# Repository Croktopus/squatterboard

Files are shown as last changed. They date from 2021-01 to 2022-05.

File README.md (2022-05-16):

# Squatterboard

NOTE: THIS PROJECT HAS BEEN SUPPLANTED BY [SQUATTERBOARD2](https://github.com/Croktopus/squatterboard2)

The primary purpose behind this daughterboard is to take up less space "vertically", in addition to using m3 screws (so it can use the same screws I use on the rest of the case) and less screws.

It's also designed to be easily JLC assembled, using basic parts where possible, and the only hand soldering that must be done is the USB and JLC connectors. using the files in the JLC directory, you can get 10 assembled for about $18, though JLC might tack on a $10 "multiple design" tax.

Due to peculiarities of the keyboard i designed this for, it's optimized to be mounted "upside down" with the USB & components on the bottom side, and it's meant to use 1.0mm FR4. Also, the pinout is not at all compatible with the Unified Daughterboard or PCBs which use it.

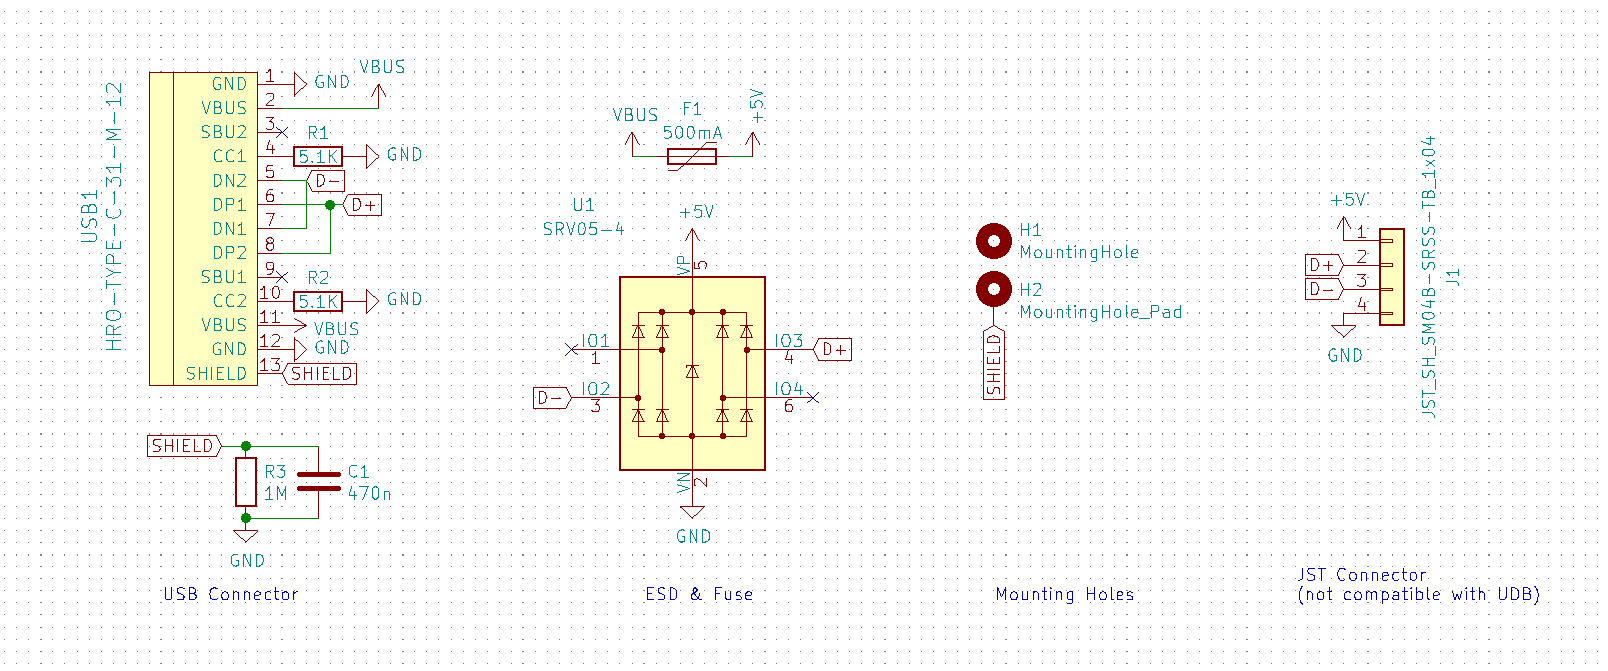
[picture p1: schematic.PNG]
schematic

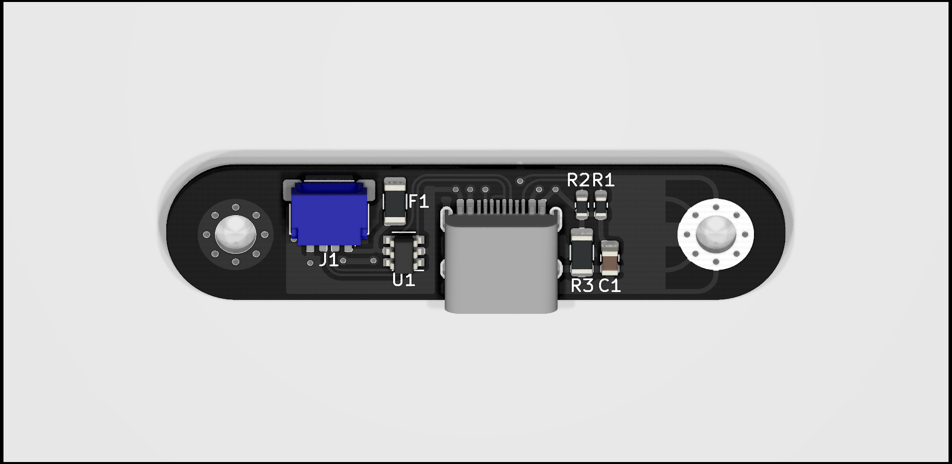
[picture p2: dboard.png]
pcb


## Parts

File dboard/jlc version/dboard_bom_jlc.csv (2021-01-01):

Comment | Designator | Footprint | LCSC Part #
470n | C1,C2 | C_0805_2012Metric | C13967
500mA | F1,F2 | Fuse_1206_3216Metric | C70076
5.1K | R1,R2,R4,R5 | R_0603_1608Metric | C23186
1M | R3,R6 | R_1206_3216Metric | C17927
SRV05-4 | U1,U2 | SOT-23-6 | C85364

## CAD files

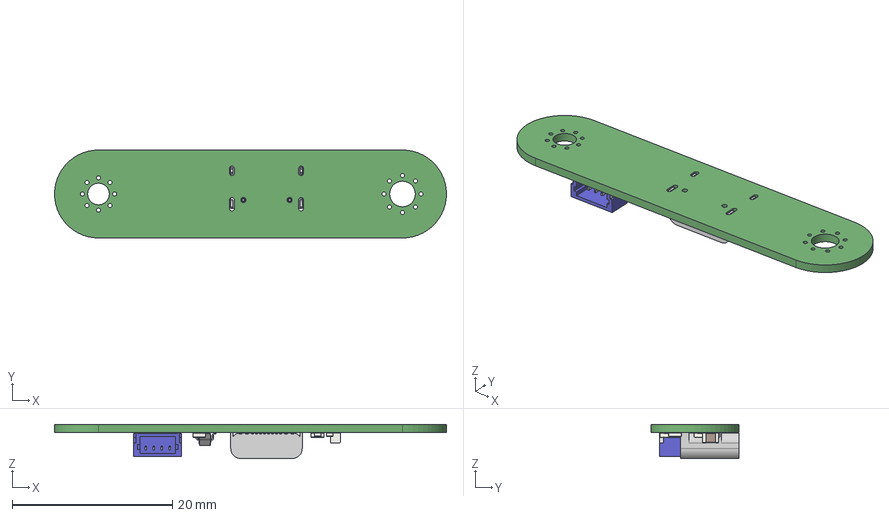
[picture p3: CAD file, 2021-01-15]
dboard/dboardm25.step
49.0 x 11.0 x 4.26 mm

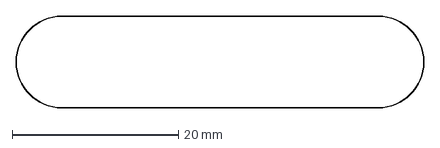
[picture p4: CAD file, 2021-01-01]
dboard/outline.dxf
49.0 x 11.0 mm

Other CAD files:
dboard/dboard.step

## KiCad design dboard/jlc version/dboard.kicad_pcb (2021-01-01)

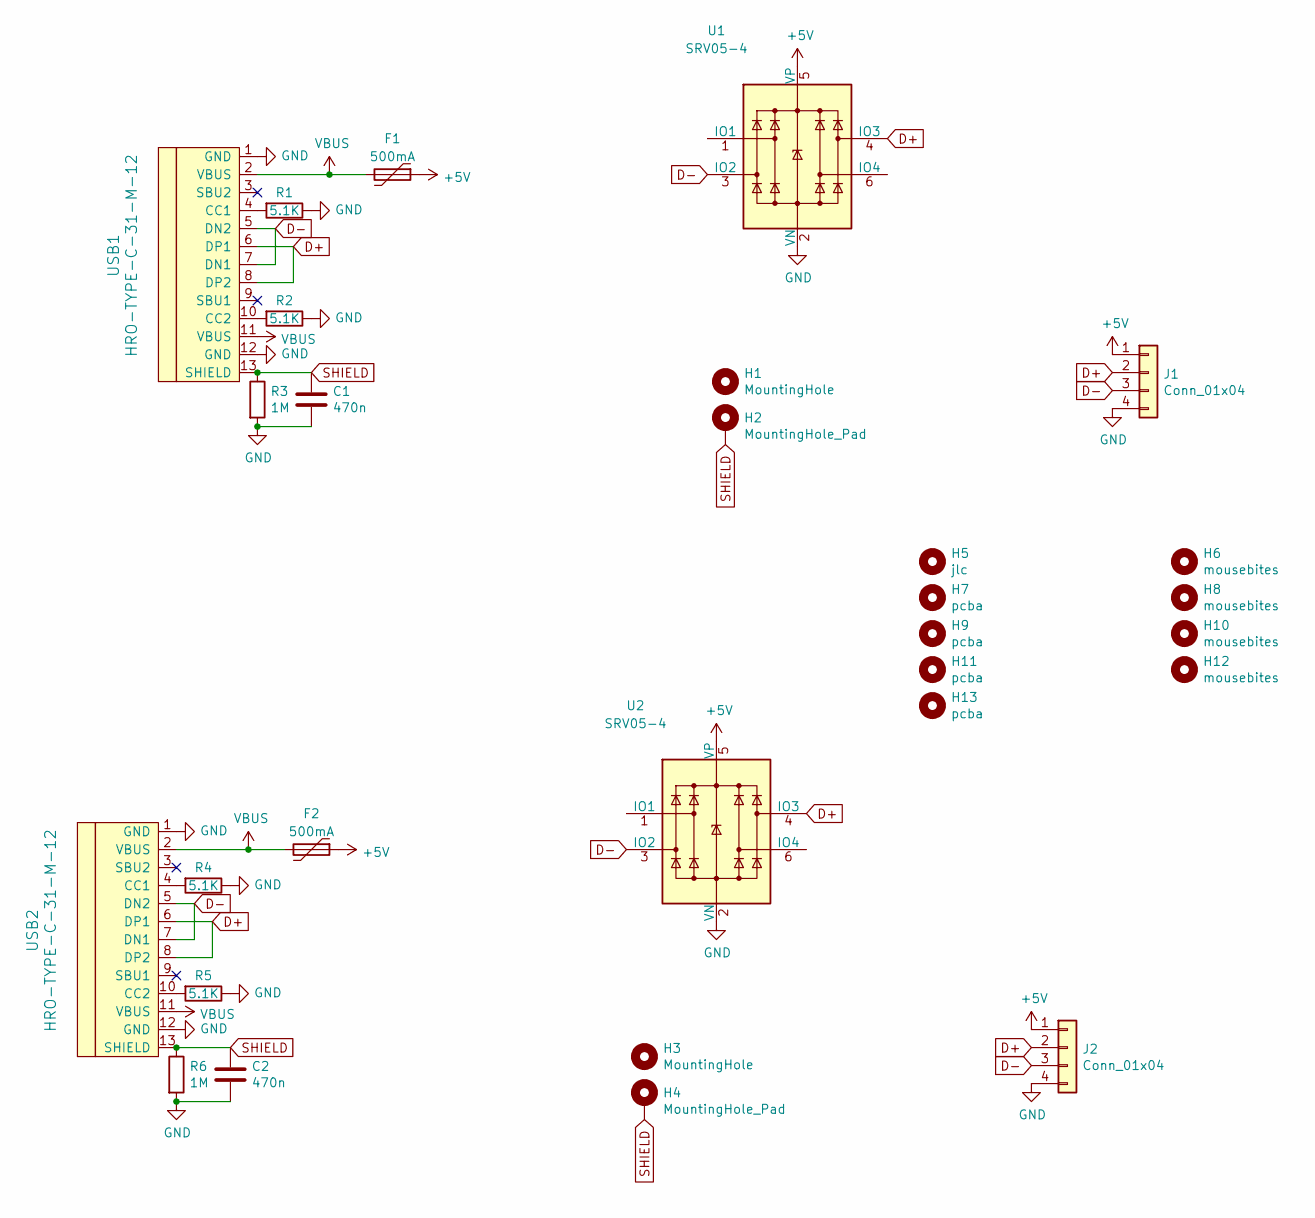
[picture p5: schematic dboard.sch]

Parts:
C1, C2: 470n; C_0805_2012Metric; jlc C13967
F1, F2: 500mA; Fuse_1206_3216Metric; jlc C70076
H1, H3: MountingHole; M3_Via_Hole_NC
H2, H4: MountingHole_Pad; M3_Via_Hole
H5: jlc
H6, H8, H10, H12: mousebites; mousebites-6mm
H7, H9, H11, H13: pcba; JLCPCBA
J1, J2: Conn_01x04; JST_SH_SM04B-SRSS-TB_1x04-1MP_P1.00mm_Horizontal
R1, R2, R4, R5: 5.1K; R_0603_1608Metric; jlc C23186
R3, R6: 1M; R_1206_3216Metric; jlc C17927
U1, U2: SRV05-4; SOT-23-6; jlc C85364
USB1, USB2: HRO-TYPE-C-31-M-12; HRO-TYPE-C-31-M-12-Assembly

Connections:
+5V: F1.1, F2.1, J1.1, J2.1, U1.5 (VP), U2.5 (VP)
D+: J1.2, J2.2, U1.4 (IO3), U2.4 (IO3), USB1.6 (DP1), USB1.8 (DP2), USB2.6 (DP1), USB2.8 (DP2)
D-: J1.3, J2.3, U1.3 (IO2), U2.3 (IO2), USB1.5 (DN2), USB1.7 (DN1), USB2.5 (DN2), USB2.7 (DN1)
GND: C1.2, C2.2, J1.4, J2.4, R1.1, R2.1, R3.2, R4.1, R5.1, R6.2, U1.2 (VN), U2.2 (VN), USB1.1 (GND), USB1.12 (GND), USB2.1 (GND), USB2.12 (GND)
unnamed: R1.2, USB1.4 (CC1)
unnamed: R2.2, USB1.10 (CC2)
unnamed: R4.2, USB2.4 (CC1)
unnamed: R5.2, USB2.10 (CC2)
SHIELD: C1.1, C2.1, H2.1, H4.1, R3.1, R6.1, USB1.13 (SHIELD), USB2.13 (SHIELD)
VBUS: F1.2, F2.2, USB1.2 (VBUS), USB1.11 (VBUS), USB2.2 (VBUS), USB2.11 (VBUS)

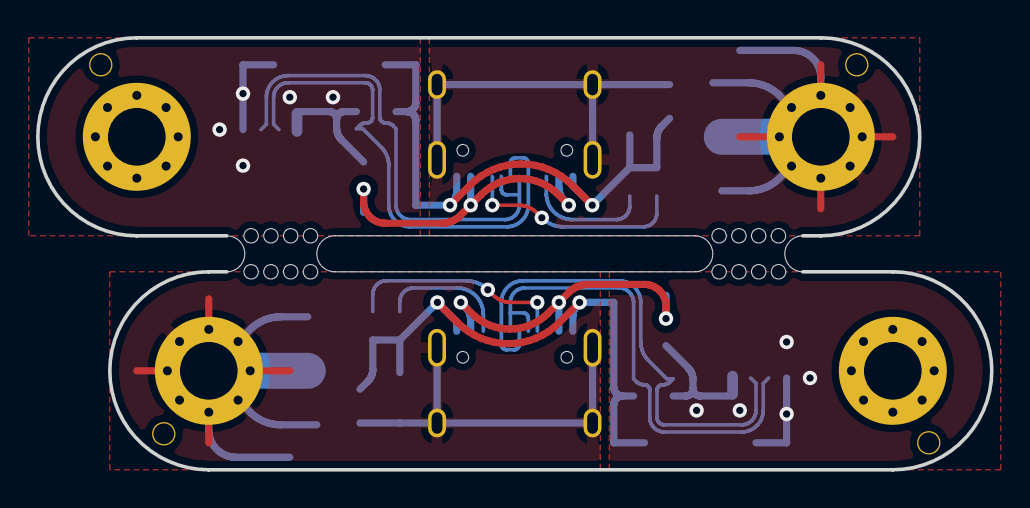
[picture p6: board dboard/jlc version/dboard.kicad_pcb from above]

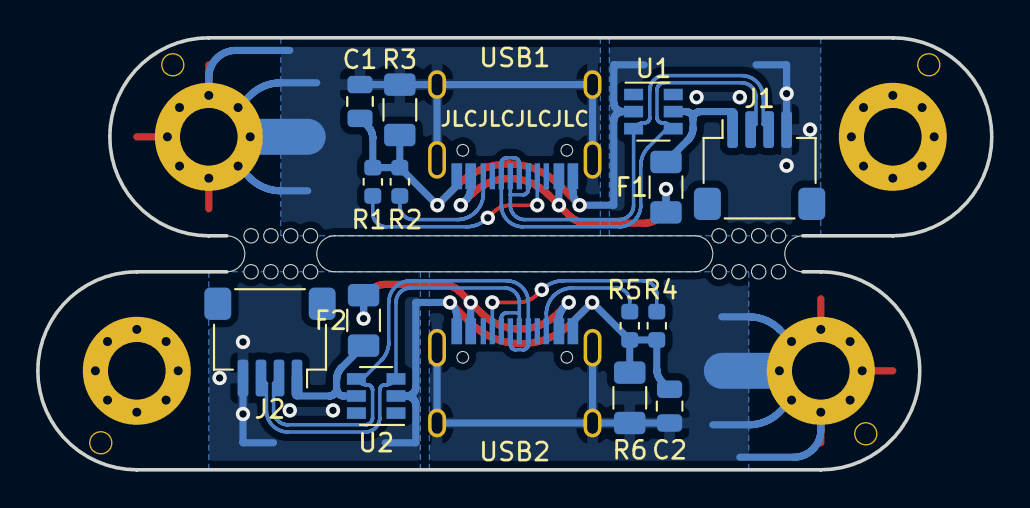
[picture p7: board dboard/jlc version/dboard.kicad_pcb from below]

Board: 2 copper layers, 53.0 x 24.0 mm, 29 parts (17 on the bottom side), 10 nets.

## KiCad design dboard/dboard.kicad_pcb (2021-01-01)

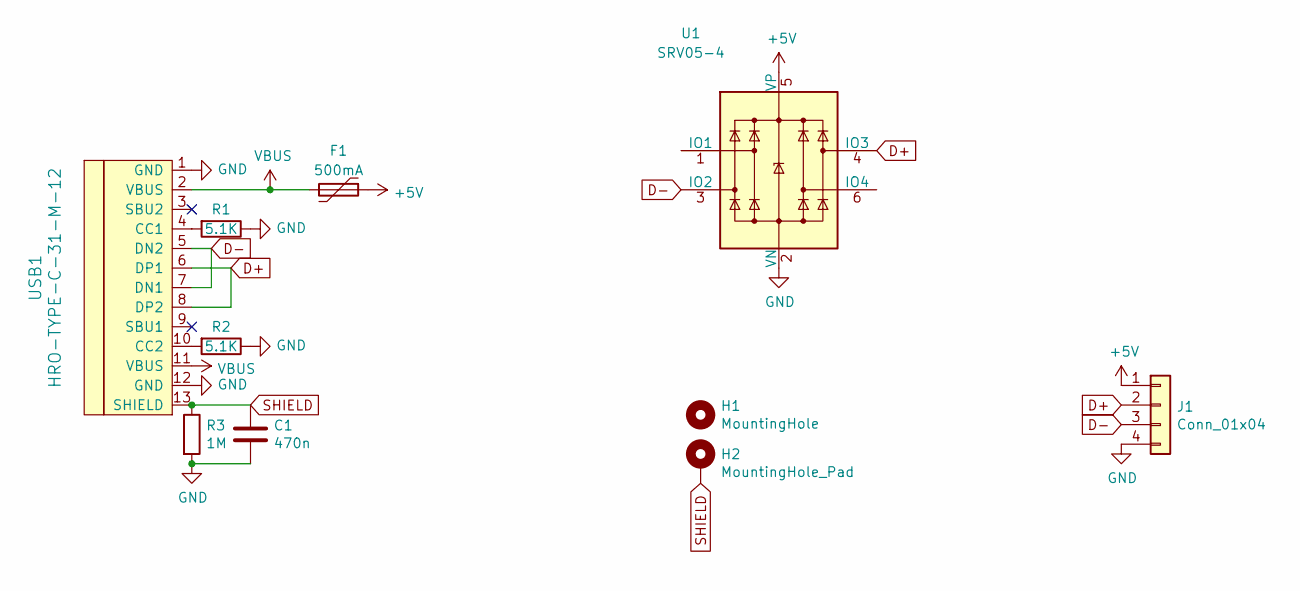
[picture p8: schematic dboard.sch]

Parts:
C1: 470n; C_0805_2012Metric; jlc C13967
F1: 500mA; Fuse_1206_3216Metric; jlc C70076
H1: MountingHole; M3_Via_Hole_NC
H2: MountingHole_Pad; M3_Via_Hole
J1: Conn_01x04; JST_SH_SM04B-SRSS-TB_1x04-1MP_P1.00mm_Horizontal
R1, R2: 5.1K; R_0603_1608Metric; jlc C23186
R3: 1M; R_1206_3216Metric; jlc C17927
U1: SRV05-4; SOT-23-6; jlc C85364
USB1: HRO-TYPE-C-31-M-12; HRO-TYPE-C-31-M-12-Assembly

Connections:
+5V: F1.1, J1.1, U1.5 (VP)
D+: J1.2, U1.4 (IO3), USB1.6 (DP1), USB1.8 (DP2)
D-: J1.3, U1.3 (IO2), USB1.5 (DN2), USB1.7 (DN1)
GND: C1.2, J1.4, R1.1, R2.1, R3.2, U1.2 (VN), USB1.1 (GND), USB1.12 (GND)
unnamed: R1.2, USB1.4 (CC1)
unnamed: R2.2, USB1.10 (CC2)
SHIELD: C1.1, H2.1, R3.1, USB1.13 (SHIELD)
VBUS: F1.2, USB1.2 (VBUS), USB1.11 (VBUS)

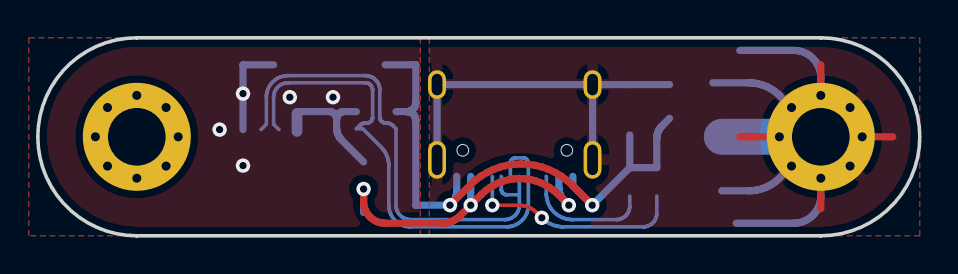
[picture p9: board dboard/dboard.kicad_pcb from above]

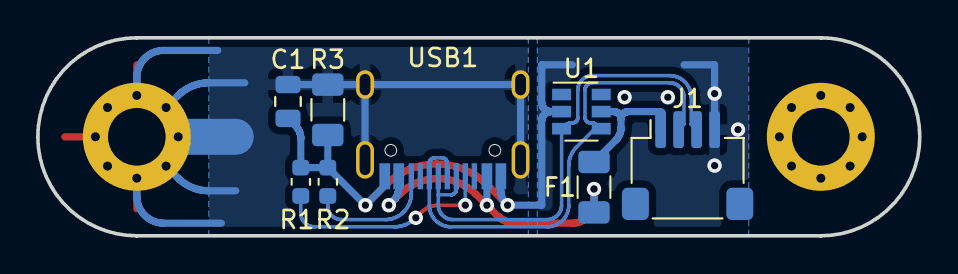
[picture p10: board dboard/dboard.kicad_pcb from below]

Board: 2 copper layers, 49.0 x 11.0 mm, 10 parts (8 on the bottom side), 8 nets.

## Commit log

2021-01-01 electrics, jlc files
    [dboard outline.dxf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]
2021-01-01 separated jlc files
    [dboard outline.dxf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]
2021-01-15 added images
    [dboard.sch, dboardm25.step]
